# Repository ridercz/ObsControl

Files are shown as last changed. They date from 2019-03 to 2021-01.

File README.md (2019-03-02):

# OBS Control Rig

This is my OBS control rig. I prefer hardware buttons for switching scenes etc., so I built myself a control panel. It's based on Arduino Pro Micro (ATmega32u4) and uses arcade buttons.

* **[OBS Control Firmware](ObsControlFirmware)** is Arduino sketch that emulates USB keyboard.
* **[MK1](MK1)** is first model of casing, which is partially 3D printed and has exchangeable paper covers covered by acrylic.
* **MK2** will be completely lasercut to overcome problems with 3D printing such large object etc.

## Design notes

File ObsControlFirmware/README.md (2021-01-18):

# OBS Control Firmware

This is sketch for Arduino Pro Micro or other ATmega32u4-based Arduino board. It handles button presses and emulates USB keyboard.

It recognizes two types of buttons:

1. _Standard buttons_, which simply send the keystroke to computer. I use them for switching scenes 1-5. Their state can be indicated with optional RGB LED (I use APA106, but any neopixel-style LED can be used).
2. _Status buttons_, which toggle states and can turn on/off LEDs. I use the backlighted buttons for stream and record control. Again they send keystrokes to computer. The status management is done only in controller, no backwards communication occurs.

As a keystroke I use _Ctrl+Alt+Shift+F1_ for first standard button, _Ctrl+Alt+Shift+F2_ for second etc. The status button follows.

So, with this firmware I use the following mapping:

Command                           | Keystroke
----------------------------------|------------------
Switch to scene "Camera only"     | Ctrl+Alt+Shift+F1
Switch to scene "Screen only"     | Ctrl+Alt+Shift+F2
Switch to scene "Screen + camera" | Ctrl+Alt+Shift+F3
Switch to scene "Brand loop 1"    | Ctrl+Alt+Shift+F4
Switch to scene "Brand loop 2"    | Ctrl+Alt+Shift+F5
Start/stop recording              | Ctrl+Alt+Shift+F6
Start/stop streaming              | Ctrl+Alt+Shift+F7

## Hardware connection

For _Pro Micro_ board I recommend to solder pins upside down (so they stick out of component side) so the flat board side can be hotglued to the box.

PIN | Connect
--- | -------
D2  | Red button
D3  | Blue button
D4  | Black  button
D5  | Yellow button
D6  | Green  button
D7  | Square green button (stream)
D8  | Square red button (record)
D14 | Square red LED (record)
D15 | Square green LED (stream)
D16 | RGB LED Data in
VCC | RGB LED power
GND | Common ground (buttons & LEDs)

## Example wiring

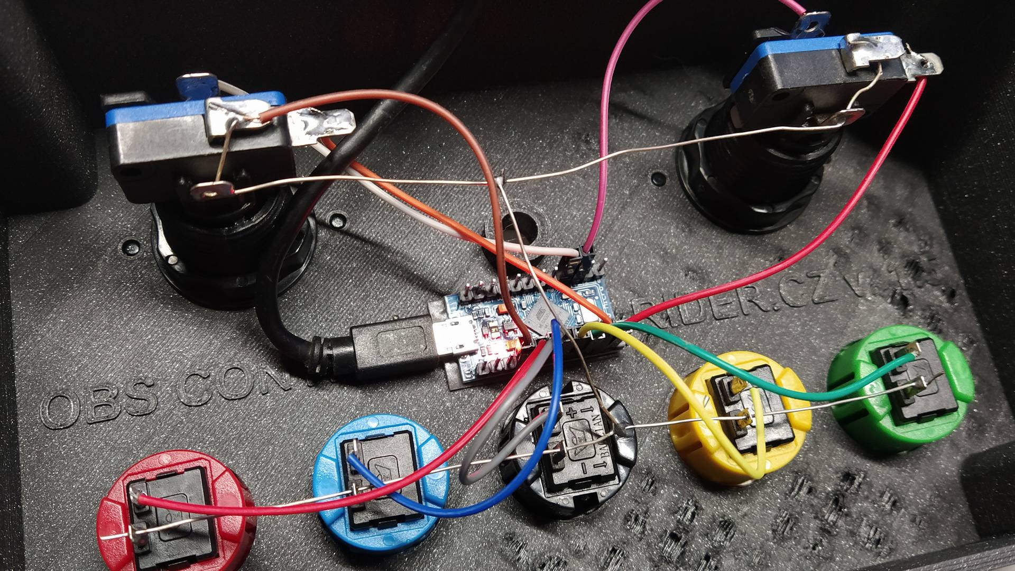
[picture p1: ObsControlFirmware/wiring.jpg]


MK1 from bottom side. Does not include the RGB LED.

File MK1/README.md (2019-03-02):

# OBS Control Rig MK1

This is the first version, which combines 3D printing, laser cutting and plotter cutting. The results are not as satisfactory as I hoped, printing such large object is slow and I was unable to print it flawlessly. I intend to make MK2, which will be completely laser cut.

* 3D printing
  * [`ObsControl.scad`](ObsControl.scad) - parametric OpenSCAD model
  * [`ObsControl_1.5.stl`](ObsControl_1.5.stl) - resulting STL model
* Cutting
  * [`ObsControl.ai`](ObsControl.ai) - vector file containing layers for printing, paper cutting and laser cutting & engraving.
  * [`ObsControl_laser.ai`](ObsControl_laser.ai) - vector file for laser cutting and engraving. The circle under logo is diffusor for status LED, which is not used at the time being.
  * [`ObsControl_plotter.studio3`](ObsControl_plotter.studio3) - Silhouette Studio file for paper printing and cutting.

## Front View

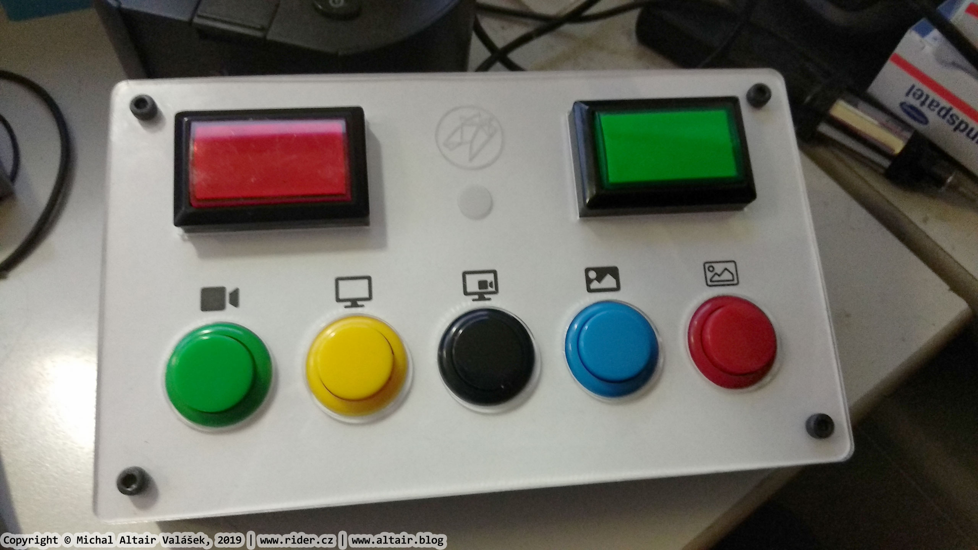
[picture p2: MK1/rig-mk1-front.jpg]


## Back View

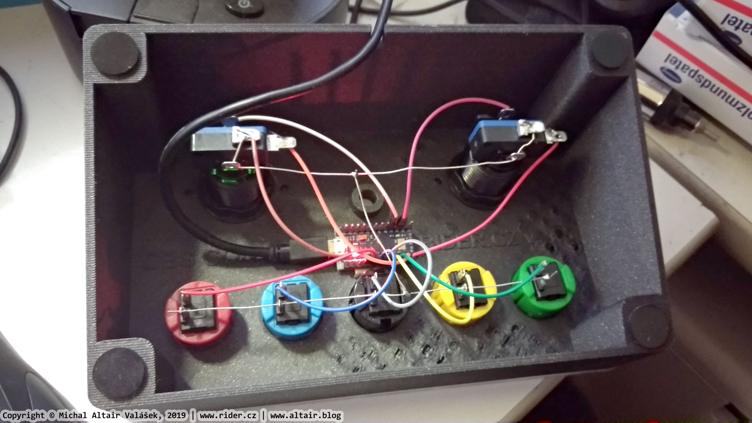
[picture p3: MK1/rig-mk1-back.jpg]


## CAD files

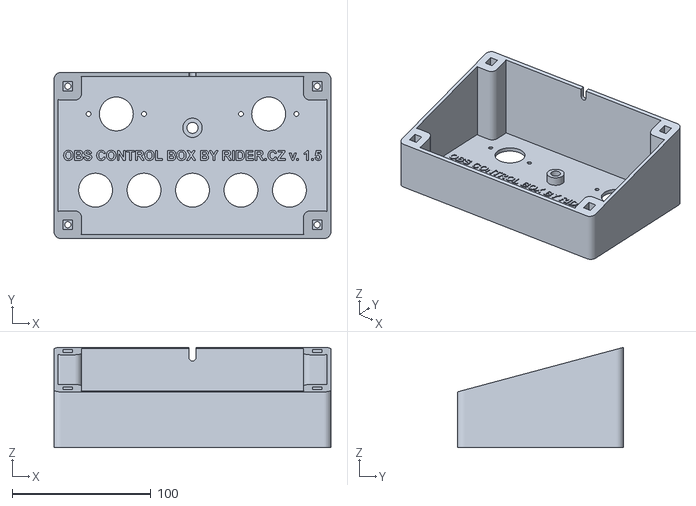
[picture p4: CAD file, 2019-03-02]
MK1/ObsControl_1.5.stl
200.0 x 120.0 x 72.4

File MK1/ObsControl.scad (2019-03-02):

outer_dimensions = [200, 120, 100];
min_height = 40;
corner_radius = 5;
mode_button_x = [45, 155];
mode_button_y = 90;
mode_button_d = 24.5;
mode_button_kd = 3.5;
mode_button_ks = 40;
scene_button_x = [30, 65, 100, 135, 170];
scene_button_y = 35;
scene_button_d = 24.5;
led_hole_dia = 8;
led_hole_pos = [100, 80];
led_height = 10;
wall_thickness = 3;
screw_hole_diameter = 4.5;
screw_hole_distance = 10;
screw_nut_diameter = 10;
screw_nut_sides = 4;
skew = 15;
cable_hole_diameter = 5;
cable_hole_distance = 65;
version = "OBS CONTROL BOX BY RIDER.CZ v. 1.5";

fudge = 1;
$fn = 32;

inner_dimensions = [
    outer_dimensions[0] - 2 * wall_thickness, 
    outer_dimensions[1] - 2 * wall_thickness, 
    outer_dimensions[2] - wall_thickness + fudge
];

difference() {
    // Main shape
    union() {
        // Basic box
        difference() {
            rcube(outer_dimensions, corner_radius);
            translate([wall_thickness, wall_thickness, wall_thickness]) rcube(inner_dimensions, corner_radius - wall_thickness);
        }

        // LED shield
        translate(led_hole_pos) cylinder(d = led_hole_dia + 2 * wall_thickness, h = led_height);

        // Screw pillars
        for(x = [0, outer_dimensions[0] - screw_hole_distance * 2], y  = [0, outer_dimensions[1] - screw_hole_distance * 2]) translate([x, y]) rcube([screw_hole_distance * 2, screw_hole_distance * 2, outer_dimensions[2]], corner_radius);

        // Version
        translate([outer_dimensions[0] / 2, outer_dimensions[1] / 2, wall_thickness]) linear_extrude(.6) 
            text(text = version, font = "Arial:bold", size = 7.2, halign = "center", valign = "center");
    }

    // Screw holes
    for(x = [0, outer_dimensions[0] - screw_hole_distance * 2], y  = [0, outer_dimensions[1] - screw_hole_distance * 2]) translate([x, y]) {
        translate([screw_hole_distance, screw_hole_distance, -fudge]) cylinder(d = screw_hole_diameter, h = outer_dimensions[1] + 2 * fudge);
        translate([screw_hole_distance, screw_hole_distance, wall_thickness * 3]) rotate(180 / screw_nut_sides) cylinder(d = screw_nut_diameter, h = outer_dimensions[1], $fn = screw_nut_sides);
    }

    // Panel holes
    hh = wall_thickness + 2 * fudge;
    translate([0, 0, -fudge]) {
        // LED
        translate(led_hole_pos) cylinder(d = led_hole_dia, h = led_height + 2 * fudge);

        // Scene buttons
        for(x = scene_button_x) {
            translate([x, scene_button_y]) cylinder(d = scene_button_d, h = hh);
        }

        // Mode button
        for(x = mode_button_x) {
            translate([x, mode_button_y]) {
                cylinder(d = mode_button_d, h = hh);
                translate([-mode_button_ks / 2, 0]) cylinder(d = mode_button_kd, h = hh);
                translate([+mode_button_ks / 2, 0]) cylinder(d = mode_button_kd, h = hh);
            }
        }
    }

    // General skew
    translate([-fudge, -fudge, min_height]) rotate([skew, 0, 0]) cube(max(outer_dimensions) + 2 * fudge);

    // Cable hole
    translate([outer_dimensions[0] / 2, outer_dimensions[1] - wall_thickness - fudge, cable_hole_distance]) {
        rotate([-90, 0,0]) cylinder(d = cable_hole_diameter, h = wall_thickness + 2 * fudge);
        translate([-cable_hole_diameter / 2, 0]) cube([cable_hole_diameter, wall_thickness + 2 * fudge, outer_dimensions[2]]);
    }
}

module rcube(size, radius) {
    if(len(radius) == undef) {
        // The same radius on all corners
        rcube(size, [radius, radius, radius, radius]);
    } else if(len(radius) == 2) {
        // Different radii on top and bottom
        rcube(size, [radius[0], radius[0], radius[1], radius[1]]);
    } else if(len(radius) == 4) {
        // Different radius on different corners
        hull() {
            // BL
            if(radius[0] == 0) cube([1, 1, size[2]]);
            else translate([radius[0], radius[0]]) cylinder(r = radius[0], h = size[2]);
            // BR
            if(radius[1] == 0) translate([size[0] - 1, 0]) cube([1, 1, size[2]]);
            else translate([size[0] - radius[1], radius[1]]) cylinder(r = radius[1], h = size[2]);
            // TR
            if(radius[2] == 0) translate([size[0] - 1, size[1] - 1])cube([1, 1, size[2]]);
            else translate([size[0] - radius[2], size[1] - radius[2]]) cylinder(r = radius[2], h = size[2]);
            // TL
            if(radius[3] == 0) translate([0, size[1] - 1]) cube([1, 1, size[2]]);
            else translate([radius[3], size[1] - radius[3]]) cylinder(r = radius[3], h = size[2]);
        }
    } else {
        echo("ERROR: Incorrect length of 'radius' parameter. Expecting integer or vector with length 2 or 4.");
    }
}

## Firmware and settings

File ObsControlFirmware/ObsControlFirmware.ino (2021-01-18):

/* 
 * OBS STUDIO CONTROL RIG version 2.0 (2021-01-18)
 * 
 * Copyright (c) Michal Altair Valasek, 2019-2021
 * Licensed under terms of the MIT License.
 * 
 * https://www.rider.cz
 * https://www.altair.blog
 * https://github.com/ridercz/ObsControl/
 * 
 */

#include <Pushbutton.h>
#include <Keyboard.h>
#include <Adafruit_NeoPixel.h>

// Uncomment the following line to print values to serial instead of sending keypresses
// #define WHATIF

// How long should the key be down?
#define KEYPRESS_LENGTH         50 // ms

// POST LED blinking
#define TEST_LED_COUNT          5
#define TEST_LED_SPEED          100 // ms

// Define pins and count for standard buttons
#define STANDARD_BUTTON_COUNT   5
Pushbutton standardButtons[] {
  Pushbutton(6),                // Green  (Ctrl-Shift-Alt-F1)
  Pushbutton(5),                // Yellow (Ctrl-Shift-Alt-F2)
  Pushbutton(4),                // Black  (Ctrl-Shift-Alt-F3)
  Pushbutton(3),                // Blue   (Ctrl-Shift-Alt-F4)
  Pushbutton(2),                // Red    (Ctrl-Shift-Alt-F5)
};

// Define pins and count for LED status buttons
#define STATUS_BUTTON_COUNT     2
#define STATUS_BUTTON_LED       14
Pushbutton statusButtons[] {
  Pushbutton(8),                // Square red   (Ctrl-Shift-Alt-F6)
  Pushbutton(7),                // Square green (Ctrl-Shift-Alt-F7)
};
bool statusCurrent[STATUS_BUTTON_COUNT];

// Define pin for RGB LED APA106
// Comment the following line to disable the RGB LED functionality
#define RGB_PIN                 16
#ifdef RGB_PIN
Adafruit_NeoPixel pixels = Adafruit_NeoPixel(1, RGB_PIN, NEO_RGB + NEO_KHZ800);
unsigned long buttonColors[] = {
  0x00ff00,                     // Green
  0xffff00,                     // Yellow
  0xffffff,                     // White (black button)
  0x0000ff,                     // Blue
  0xff0000                      // Red
 };
#endif

void setup() {
#ifdef WHATIF
  while (!Serial);
  Serial.begin(9600);
  delay(500);
  Serial.print("Initializing...");
#endif

#ifdef RGB_PIN
  // Initialize RGB LED
  pixels.begin();
  pixels.fill(0xff0000); pixels.show(); delay(TEST_LED_SPEED * TEST_LED_COUNT); // Red
  pixels.fill(0x00ff00); pixels.show(); delay(TEST_LED_SPEED * TEST_LED_COUNT); // Green
  pixels.fill(0x0000ff); pixels.show(); delay(TEST_LED_SPEED * TEST_LED_COUNT); // Blue
  pixels.fill(0x000000); pixels.show();                                         // Black (off)
#endif

  // Initialize status buttons
  for (int i = 0; i < STATUS_BUTTON_COUNT; i++) {
    statusCurrent[i] = false;
    pinMode(STATUS_BUTTON_LED + i, OUTPUT);
    for(int j = 0; j < TEST_LED_COUNT; j++) {
      digitalWrite(STATUS_BUTTON_LED + i, HIGH);
      delay(TEST_LED_SPEED);
      digitalWrite(STATUS_BUTTON_LED + i, LOW);
      delay(TEST_LED_SPEED);
    }
  }

#ifdef WHATIF
  Serial.println("Done");
#endif
}

void loop() {
  // Initialize standard buttons
  for (int i = 0; i < STANDARD_BUTTON_COUNT; i++) {
    if (standardButtons[i].getSingleDebouncedPress()) pressStandardButton(i);
  }

  // Initialize status buttons
  for (int i = 0; i < STATUS_BUTTON_COUNT; i++) {
    if (statusButtons[i].getSingleDebouncedPress()) pressStatusButton(i);
  }
}

void pressStandardButton(int index) {
#ifdef WHATIF
  Serial.print("Pressed standard button #");
  Serial.println(index + 1);
#else
  sendFunctionKey(index);
#endif
#ifdef RGB_PIN
  pixels.fill(buttonColors[index]);
  pixels.show();
#endif
}

void pressStatusButton(int index) {
  statusCurrent[index] = !statusCurrent[index];
  digitalWrite(STATUS_BUTTON_LED + index, statusCurrent[index]);
#ifdef WHATIF
  Serial.print("Status button #");
  Serial.print(index + 1);
  Serial.println(statusCurrent[index] ? " enabled" : " disabled");
#else
  sendFunctionKey(index + STANDARD_BUTTON_COUNT);
#endif
}

void sendFunctionKey(int index) {
  Keyboard.press(KEY_LEFT_CTRL);
  Keyboard.press(KEY_LEFT_SHIFT);
  Keyboard.press(KEY_LEFT_ALT);
  Keyboard.press(KEY_F1 + index);
  delay(KEYPRESS_LENGTH);
  Keyboard.releaseAll();
}

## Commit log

2021-01-14 Add labels for square buttons
2021-01-14 Add startup blinking LEDs.
2021-01-18 Add RGB status LED
